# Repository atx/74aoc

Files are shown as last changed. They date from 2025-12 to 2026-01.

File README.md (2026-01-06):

# 74aoc

<p align="center">
  
</p>

A PCB solving [Advent of Code 2025 Day 1](https://adventofcode.com/2025/day/1) using 125 discrete 74-series logic chips synthesized via an automated Hardcaml -> nextpnr -> KiCad pipeline.

**Full writeup can be found on [my blog](https://atx.name/electronics/hardcaml-to-74-series-logic).**

<p align="center">
  
</p>

Quick orientation guide:

 * `pcb/` contains the KiCad files. For reproducibility, those are "cooked" files that include the solution design loaded and routed (revert the appropriate commits for a fresh blank slate)
 * `hdl/` contains the Hardcaml source code and the Yosys+nextpnr orchestration. Some of the intermediate files are also commited for traceability. 
   * `dune exec ./test_solution.exe` runs the Hardcaml test bench
   * `dune exec ./build_solution.exe` outputs the Verilog source code from the Hardcaml solution (beware that this requires the preview version 0.18 of Hardcaml)
   * `top.v` includes the output of the previous step and wraps it to assign concrete IO pads to the signals
   * `./simulate.sh <preplace|pnr>` runs the Verilog testbench using Verilator, either on pre-placement Verilog or on the placement result from Nextpnr (using the appropriate cell models from nextpnr-generic)
 * The root directory contains several scripts that serve to translate results from `hdl` into `pcb`. Loading new design is done by running `translate_nets_to_kicad.py` and `load_luts_into_kicad.py`.
 * `controller/` this contains the bit banged driver for the board, to be executed on Raspberry Pi. Executed as `dune exec ./main.exe`, supports `--help`.

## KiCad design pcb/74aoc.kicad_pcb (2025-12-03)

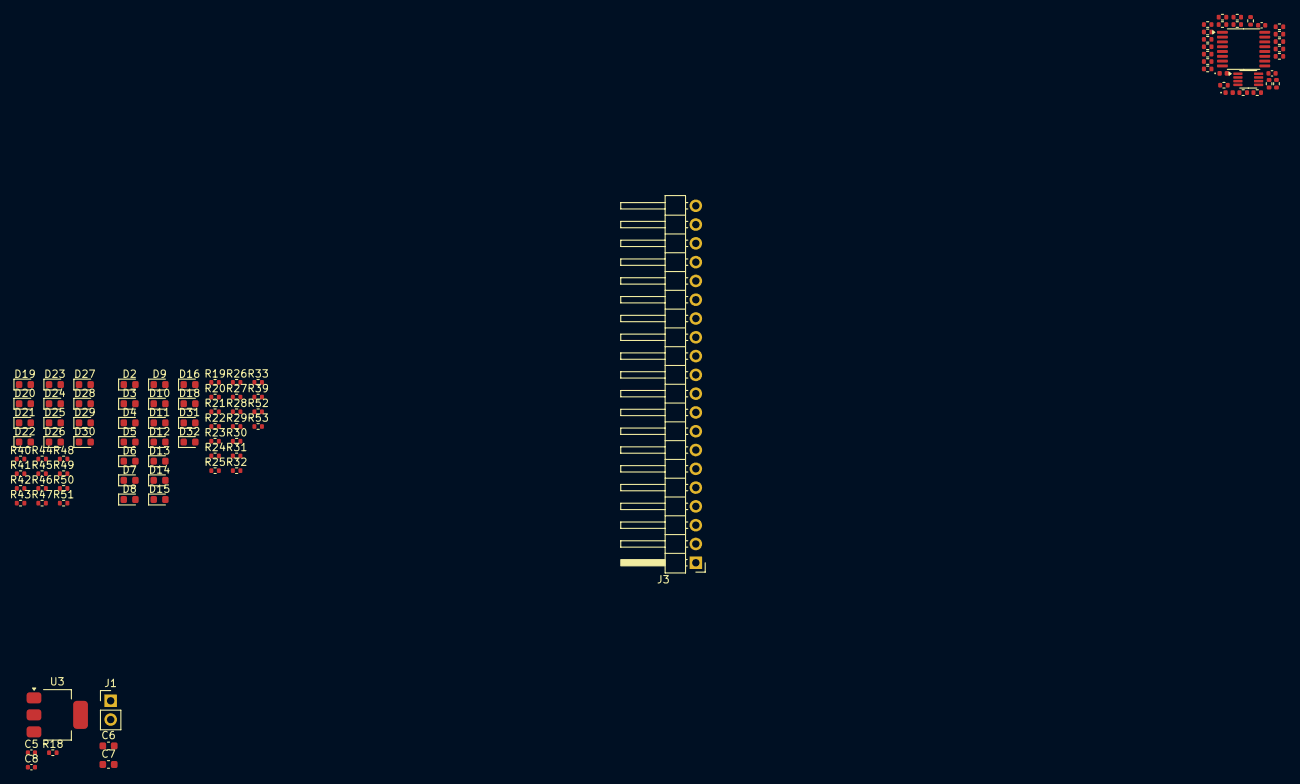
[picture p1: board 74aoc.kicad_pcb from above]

Board: 2 copper layers, 96 parts (0 on the bottom side), 66 nets, no tracks yet.

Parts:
C1, C2, C5, C8: 100n; C_0402_1005Metric
C6, C7: 10u; C_0603_1608Metric
D1, D17: LED; LED_0402_1005Metric
D2, D3, D4, D5, D6, D7, D8, D9, D10, D11, D12, D13, D14, D15, D16, D18, D19, D20, D21, D22, D23, D24, D25, D26, D27, D28, D29, D30, D31, D32: LED; LED_0603_1608Metric
J1: Conn_01x02_Pin; PinHeader_1x02_P2.54mm_Vertical
J3: Conn_01x20_Pin; PinHeader_1x20_P2.54mm_Horizontal
R1, R2, R3, R4, R5, R6, R7, R8, R9, R10, R11, R12, R13, R14, R15, R16: 1k; R_0402_1005Metric
R17, R19, R20, R21, R22, R23, R24, R25, R26, R27, R28, R29, R30, R31, R32, R33, R34, R39, R40, R41, R42, R43, R44, R45, R46, R47, R48, R49, R50, R51, R52, R53: 10k; R_0402_1005Metric
R18: 1; R_0402_1005Metric
R35, R36: 0; R_0402_1005Metric
R37, R38: 100k; R_0402_1005Metric
U1: MC74HC151ADTR2G; TSSOP-16_4.4x5mm_P0.65mm
U2: SN74LVC1G74; VSSOP-8_2.3x2mm_P0.5mm
U3: AMS1117-3.3; SOT-223-3_TabPin2

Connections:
/CELL X0 Y0/~CLR: R17.1, R35.2, U2.6 (~CLR)
/CELL X0 Y0/~PRE: R34.1, R36.2, U2.7 (~PRE)
/Power/VIN: C7.1, C8.1, J1.1, U3.3 (VI)
CLK: J3.18, R52.1, U2.1 (C)
GND: C1.2, C2.2, C5.2, C6.2, C7.2, C8.2, D2.1 (K), D3.1 (K), D4.1 (K), D5.1 (K), D6.1 (K), D7.1 (K), D8.1 (K), D9.1 (K), D10.1 (K), D11.1 (K), D12.1 (K), D13.1 (K), D14.1 (K), D15.1 (K), D16.1 (K), D18.1 (K), D19.1 (K), D20.1 (K), D21.1 (K), D22.1 (K), D23.1 (K), D24.1 (K), D25.1 (K), D26.1 (K), D27.1 (K), D28.1 (K), D29.1 (K), D30.1 (K), D31.1 (K), D32.1 (K), J1.2, J3.20, R1.1, R4.1, R6.1, R8.1, R10.1, R12.1, R14.1, R16.1, R37.1, R38.1, U1.7 (~E), U1.8 (GND), U2.4 (GND), U3.1 (GND)
NRST: J3.19, R35.1, R36.1, R53.1
unnamed: C6.1, R18.1
unnamed: D1.1 (K), R37.2
unnamed: D2.2 (A), R19.2
unnamed: D3.2 (A), R20.2
unnamed: D4.2 (A), R21.2
unnamed: D5.2 (A), R22.2
unnamed: D6.2 (A), R23.2
unnamed: D7.2 (A), R24.2
unnamed: D8.2 (A), R25.2
unnamed: D9.2 (A), R26.2
unnamed: D10.2 (A), R27.2
unnamed: D11.2 (A), R28.2
unnamed: D12.2 (A), R29.2
unnamed: D13.2 (A), R30.2
unnamed: D14.2 (A), R31.2
unnamed: D15.2 (A), R32.2
unnamed: D16.2 (A), R33.2
unnamed: D17.1 (K), R38.2
unnamed: D18.2 (A), R39.2
unnamed: D19.2 (A), R40.2
unnamed: D20.2 (A), R41.2
unnamed: D21.2 (A), R42.2
unnamed: D22.2 (A), R43.2
unnamed: D23.2 (A), R44.2
unnamed: D24.2 (A), R45.2
unnamed: D25.2 (A), R46.2
unnamed: D26.2 (A), R47.2
unnamed: D27.2 (A), R48.2
unnamed: D28.2 (A), R49.2
unnamed: D29.2 (A), R50.2
unnamed: D30.2 (A), R51.2
unnamed: D31.2 (A), R52.2
unnamed: D32.2 (A), R53.2
unnamed: R1.2, R3.2, U1.4 (I0)
unnamed: R2.2, R4.2, U1.3 (I1)
unnamed: R5.2, R6.2, U1.2 (I2)
unnamed: R7.2, R8.2, U1.1 (I3)
unnamed: R9.2, R10.2, U1.15 (I4)
unnamed: R11.2, R12.2, U1.14 (I5)
unnamed: R13.2, R14.2, U1.13 (I6)
unnamed: R15.2, R16.2, U1.12 (I7)
VCC: C1.1, C2.1, C5.1, R2.1, R3.1, R5.1, R7.1, R9.1, R11.1, R13.1, R15.1, R17.2, R18.2, R34.2, U1.16 (VCC), U2.8 (VCC), U3.2 (VO)
W_IO_I0: J3.1, R19.1
W_IO_I1: J3.2, R20.1
W_IO_I2: J3.3, R21.1
W_IO_I3: J3.4, R22.1
W_IO_I4: J3.5, R23.1
W_IO_I5: J3.6, R24.1
W_IO_I6: J3.7, R25.1
W_IO_I7: J3.8, R26.1
W_IO_I8: J3.9, R27.1
W_IO_I9: J3.10, R28.1
W_IO_I10: J3.11, R29.1
W_IO_I11: J3.12, R30.1
W_IO_I12: J3.13, R31.1
W_IO_I13: J3.14, R32.1
W_IO_I14: J3.15, R33.1
W_IO_I15: J3.16, R39.1
W_X0_Y0_F: D1.2 (A), U1.5 (Z), U2.2 (D)
W_X0_Y0_Q: D17.2 (A), U2.5 (Q)

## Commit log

2025-12-02 Initial version of the PCB
    [74aoc.kicad_pcb, 74aoc.kicad_sch, cell.kicad_sch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]
2025-12-02 Add output LED array
    [74aoc.kicad_sch, cell.kicad_sch, interface.kicad_sch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]
2025-12-03 Remove IO shift registers
    Too complex
    [74aoc.kicad_pcb, 74aoc.kicad_sch, inputs.kicad_sch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]
2025-12-03 Create a script that duplicates the cell schematic instances
    [74aoc.kicad_sch, cell.kicad_sch]
2025-12-03 Route the basic elements + power + clk + rst network
    [power.kicad_sch]
2025-12-03 Enforce K = 3 more
    The Verilog was actually generated with K = 4 since we have not set it
    in nextpnr. But, it has no practical impact since the architecture does
    not provide any wires into the fourth input...
2025-12-04 Slightly more spacious spacing of the output LEDs
2025-12-04 Add a script to translate nextpnr nets into KiCad
2025-12-05 Initialize all DFFs to 0
    Oops did not realize that nextpnr can only do 1 anyway...
    [cell.kicad_sch]
2025-12-05 Fix and finalize the KiCad loading pipeline
2025-12-06 PCB prettification
    [cell.kicad_sch]
2025-12-06 Some final PCB touches
2025-12-06 Tag unused Muxes/DFFs for not-populating
    [cell.kicad_sch]
2025-12-06 Wire unused inputs to ground
    Should be done according to the mux datasheet...
    [74aoc.kicad_sch]
2025-12-06 Add LCSC codes to everything that did not have them yet
    [cell.kicad_sch, inputs.kicad_sch, output_leds.kicad_sch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]
2025-12-07 Bake everything into the PCB (+ commit the intermediates)
    This is mostly for traceability reproducibility reasons.
    In practice, the best way to bake a different design would be to branch
    off just before this commit
    [74aoc.kicad_sch, interconnects.kicad_sch]
2025-12-07 Add JLCPCB_CORRECTION
    [cell.kicad_sch]
2025-12-29 Use Raspberry Pi specific GPIO library
    This allows faster bit banging as we do not have to do an ioctl for
    every GPIO change...
